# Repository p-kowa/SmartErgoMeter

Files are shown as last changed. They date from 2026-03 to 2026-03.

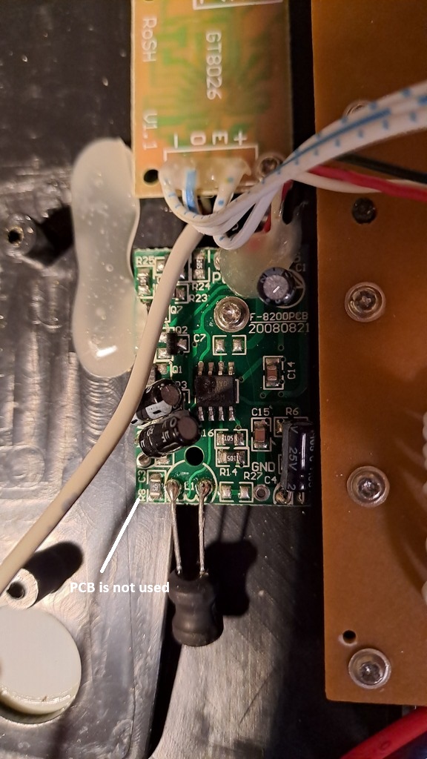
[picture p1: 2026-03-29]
pictures/chest strap receiver for pulse measurement.jpg

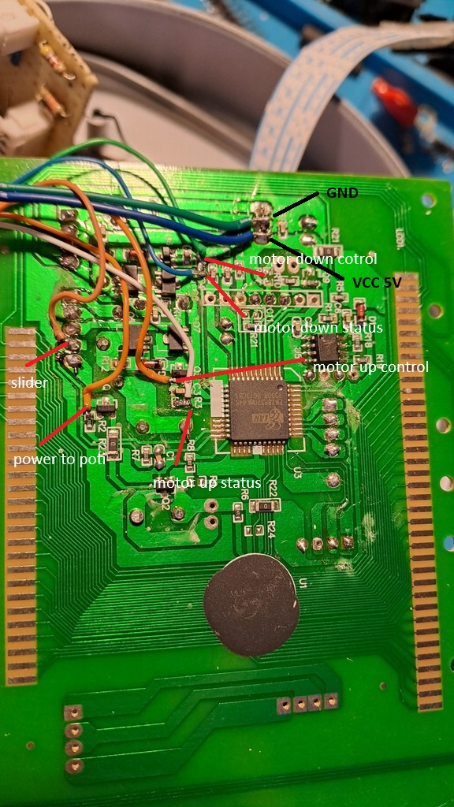
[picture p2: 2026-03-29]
pictures/wiring .jpg

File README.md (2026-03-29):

# SmartErgoMeter — Hammer Cardio XT5 Smart Trainer

Converts a **Hammer Cardio XT5** ergometer into a smart trainer compatible with fitness apps like **KinoMap**, **Zwift**, **Rouvy** etc. via BLE FTMS (Fitness Machine Service).

## Hardware

### Microcontroller
- **ESP32-C3 SuperMini** (tested ✅)
- **ESP32-S3 Zero** (target platform)

### Ergometer Components Used
The original ergometer PCB (EM78P510 controller) is left **untouched**. The ESP32 add-on board taps into existing signals.

| Component | Description |
|---|---|
| Reed contact | Speed + cadence sensor on crank (1 pulse = 1 revolution) |
| Heart rate sensor | 5V digital pulse output |
| Potentiometer | Resistance position feedback; PNP transistor on original PCB switches its supply |
| DC motor H-bridge | Original NPN H-bridge on PCB; ESP32 drives transistor bases via 8.2kΩ |
| EM78P510 MCU | Original controller; coexists via OR circuit and high-Z motor pins |

### External Circuit (add-on board)
| Component | Purpose |
|---|---|
| **BAT43** Schottky ×2 | OR-circuit: EM78-OUT1 + EM78-OUT2 → GPIO1 (EM78 activity detect) |
| **33kΩ / 68kΩ resistors** | Voltage divider: poti wiper (max ~5V) → GPIO3 (max 3.37V, safe for ESP32) |
| **10kΩ resistor** | Series resistor: reed contact line (4.7V) → GPIO2 (protects ESP32, no divider to GND) |
| **10kΩ / 18kΩ resistors** | Voltage divider: HR sensor output (5V) → GPIO7 |
| **8.2kΩ resistor ×2** | Motor base resistors: GPIO10 → H-bridge T1 base, GPIO20 → H-bridge T2 base |
| **8.2kΩ + 100kΩ resistors** | EM78_ACTIVE signal: BAT43 output → 8.2kΩ → GPIO1 → 100kΩ → GND |

### Pin Mapping
| GPIO | Signal | Notes |
|---|---|---|
| 1 | EM78_ACTIVE | OR: EM78-OUT1 + EM78-OUT2 via 2× BAT43 → 8.2kΩ → GPIO1, 100kΩ pulldown |
| 2 | Reed contact | 4.7V line via 10kΩ series, INPUT_PULLUP, FALLING interrupt |
| 3 | Potentiometer (ADC) | Wiper via 33kΩ/68kΩ divider → max 3.37V |
| 5 | Poti enable (PNP base) | Active LOW: GPIO5 LOW → PNP on → poti powered |
| 7 | Heart rate sensor | 5V via 10kΩ/18kΩ divider, INPUT, RISING interrupt |
| 10 | Motor IN_DOWN | HIGH → reduces resistance; 8.2kΩ to H-bridge transistor base |
| 20 | Motor IN_UP | HIGH → increases resistance; 8.2kΩ to H-bridge transistor base |

### Wiring Diagram
```
ESP32
│
├── GPIO2  ──[10kΩ]──────────── Reed contact line (4.7V from original PCB)
│           (INPUT_PULLUP)      (no divider to GND, EM78P510 stays unloaded)
│
├── GPIO7  ──[10kΩ]──┬───────── HR sensor output (5V)
│                    └─[18kΩ]── GND
│
├── GPIO3  ──────────┬───────── Poti wiper (via original PCB PNP switch)
│          [33kΩ between wiper and junction]
│                    └─[68kΩ]── GND
│
├── GPIO5  ── PNP base (on original PCB, via existing base resistor)
│           LOW = PNP on → poti powered
│           HIGH = PNP off → poti unpowered
│           (EM78P510 also drives same PNP via its own resistor)
│
├── GPIO1  ──[8.2kΩ]──┬─[BAT43]── EM78P510 Motor-OUT1
│          [100kΩ]    └─[BAT43]── EM78P510 Motor-OUT2
│           to GND                 (OR circuit: HIGH = EM78 driving motor)
│
├── GPIO10 ──[8.2kΩ]──────────── H-bridge transistor 1 base (Motor DOWN)
├── GPIO20 ──[8.2kΩ]──────────── H-bridge transistor 2 base (Motor UP)
│           KINOMAP: OUTPUT (ESP32 drives)
│           MANUAL:  INPUT / high-Z (EM78P510 has full control)
```

## Software

### BLE FTMS Profile
The device advertises as a **Fitness Machine Service (0x1826)** Indoor Bike with:

| Characteristic | UUID | Properties |
|---|---|---|
| Fitness Machine Feature | 0x2ACC | READ |
| Indoor Bike Data | 0x2AD2 | NOTIFY (1/sec) |
| Training Status | 0x2AD3 | NOTIFY, READ |
| Supported Resistance Level Range | 0x2AD6 | READ |
| Fitness Machine Control Point | 0x2AD9 | WRITE, INDICATE |
| Fitness Machine Status | 0x2ADA | NOTIFY |

Device name: `FTMSXXXXXXXX` (4 bytes of BLE MAC address)

### Control Modes
| Mode | Active when | Motor control |
|---|---|---|
| **KINOMAP** | BLE connected | ESP32 drives motor to target position via potentiometer feedback |
| **MANUAL** | BLE disconnected | EM78P510 buttons control motor (motor pins set to high-Z) |

When BLE connects → ESP32 gets priority (KINOMAP mode)  
When BLE disconnects → EM78P510 buttons take over (MANUAL mode)

Collision protection: if EM78_ACTIVE goes HIGH while ESP32 is driving, motor stops immediately.

### Supported FTMS Opcodes
| OpCode | Function |
|---|---|
| 0x00 | Request Control |
| 0x07 | Start / Resume |
| 0x08 | Stop / Pause |
| 0x04 | Set Target Resistance Level (SINT16, resolution 0.1, value 0–1000 = 0–100%) |
| 0x11 | Set Indoor Bike Simulation Parameters (grade → resistance mapping) |

### Calibration

The following values are calibrated for this specific Hammer Cardio XT5 unit:

```cpp
// Effective distance per crank revolution (reed is on crank, 1 pulse = 1 rev)
// Gear ratio is implicitly included — no separate GEAR_RATIO needed
// Calibration: WHEEL_CIRCUMFERENCE_MM = current_value × (display_km_h / app_km_h)
#define WHEEL_CIRCUMFERENCE_MM  6264.0   // calibrated (display=21.6 km/h, app=1.3 km/h → 377×16.6≈6264)

// Potentiometer ADC limits (12-bit: 0–4095)
// Drive motor to each end stop, read ADC from Serial: "Poti: X% (ADC=YYYY)"
#define POTI_ADC_MIN  1246   // ADC at minimum resistance end stop
#define POTI_ADC_MAX  4059   // ADC at maximum resistance end stop

// Grade → resistance mapping (OpCode 0x11)
// -10% to +20% grade → 0–100% resistance
// Adjust range after real route testing
```

## Development Setup

### Requirements
- [PlatformIO](https://platformio.org/) (VS Code extension)
- ESP32-C3 SuperMini or ESP32-S3 Zero board

### Build & Flash
```bash
# Build for ESP32-C3
pio run -e esp32-c3-devkitm-1

# Flash
pio run -e esp32-c3-devkitm-1 --target upload

# Debug build with USB CDC Serial Monitor
pio run -e esp32-c3-debug --target upload
pio device monitor -e esp32-c3-debug

# Build for ESP32-S3
pio run -e esp32-s3-devkitc-1 --target upload
```

### platformio.ini Environments
| Environment | Board | Purpose |
|---|---|---|
| `esp32-c3-devkitm-1` | ESP32-C3 | Main firmware (no USB CDC, stable BLE) |
| `esp32-c3-debug` | ESP32-C3 | With USB CDC for Serial Monitor |
| `esp32-s3-devkitc-1` | ESP32-S3 | Target platform |

### Testing without Hardware
Enable fake data mode in [src/Smartergometer.ino](src/Smartergometer.ino):
```cpp
#define FAKE_DATA 1
```
Generates synthetic speed, cadence and heart rate data for BLE testing with apps.

### Tested Apps
| App | Platform | Result |
|-----|---|---|
| nRF Connect | Android | ✅ Indoor Bike Data visible |
| KinoMap | Android / Fire TV | ✅ Resistance control working |

## Schematics
KiCad schematic files are in the [`schematics/`](schematics/) folder.

## Roadmap
- [ ] BLE Custom Characteristic for calibration (WHEEL_CIRCUMFERENCE, POTI_ADC_MIN/MAX) with NVS persistence
- [ ] Home Assistant integration
- [ ] Grade → resistance curve tuning after real route test

## License
MIT

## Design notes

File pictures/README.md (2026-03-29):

# Pictures — SmartErgoMeter

This folder contains reference photos of the hardware components and wiring used in the SmartErgoMeter project (Hammer Cardio XT5 Smart Trainer conversion).

## Contents

| File | Description |
|---|---|
| `buttons and reed.jpg` | Buttons on the ergometer and the reed contact used as speed/cadence sensor on the flywheel |
| `chest strap receiver for pulse measurement.jpg` | Heart rate receiver module that reads the 5V digital pulse signal from the chest strap. Not used in project. |
| `motor and reed.jpg` | DC motor responsible for resistance control together with the reed contact placement |
| `pulse.jpg` | Pulse/heart rate signal detail |
| `rotary potentiometer.jpg` | Rotary potentiometer used for resistance position feedback (only powered when motor runs) |
| `Temp PCB.jpg` | Temporary PCB / prototype circuit board with the external components (DRV8833, BS170, voltage dividers) |
| `wiring .jpg` | Overall wiring of the setup connecting the ESP32 to the ergometer components |

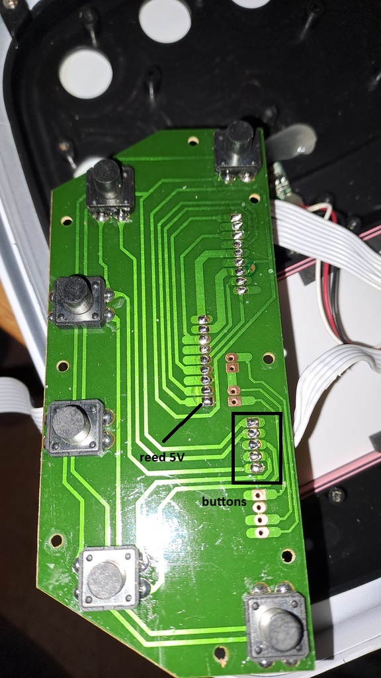
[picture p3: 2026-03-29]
pictures/buttons and reed.jpg

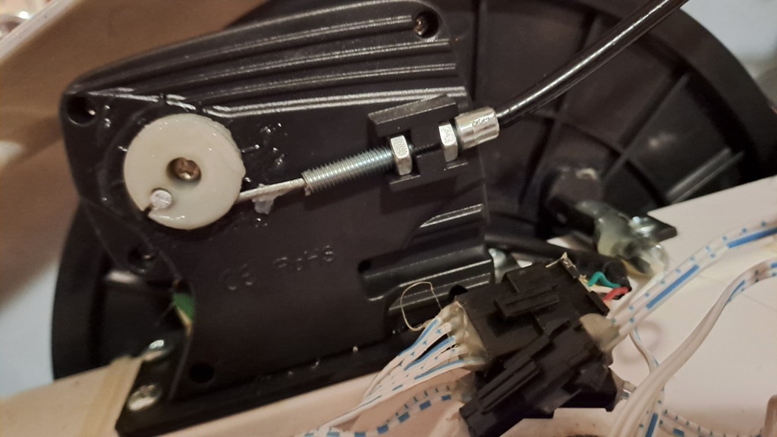
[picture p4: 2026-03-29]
pictures/motor and reed.jpg

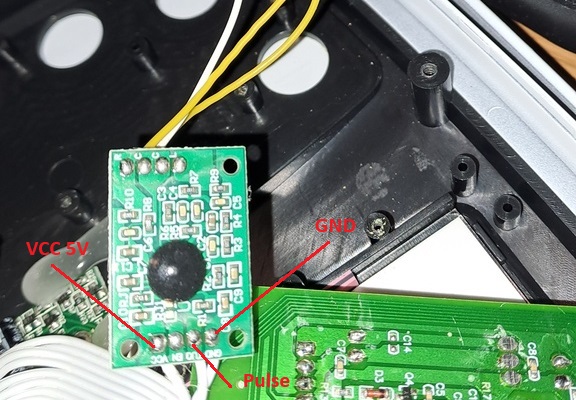
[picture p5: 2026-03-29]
pictures/pulse.jpg

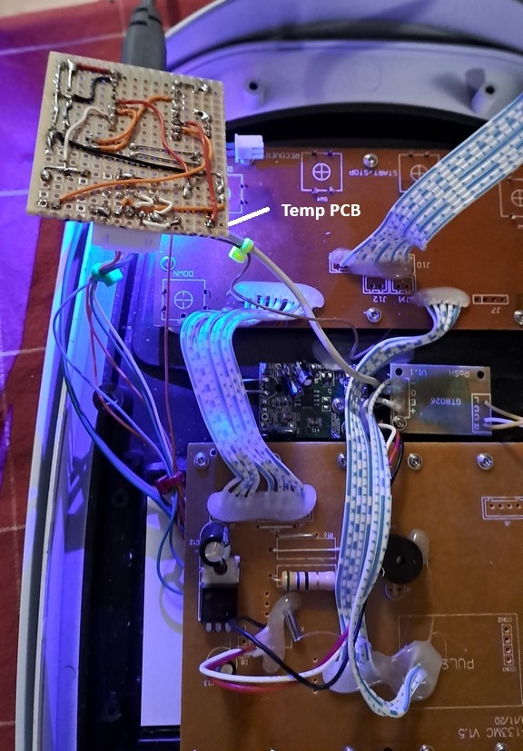
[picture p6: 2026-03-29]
pictures/Temp PCB.jpg

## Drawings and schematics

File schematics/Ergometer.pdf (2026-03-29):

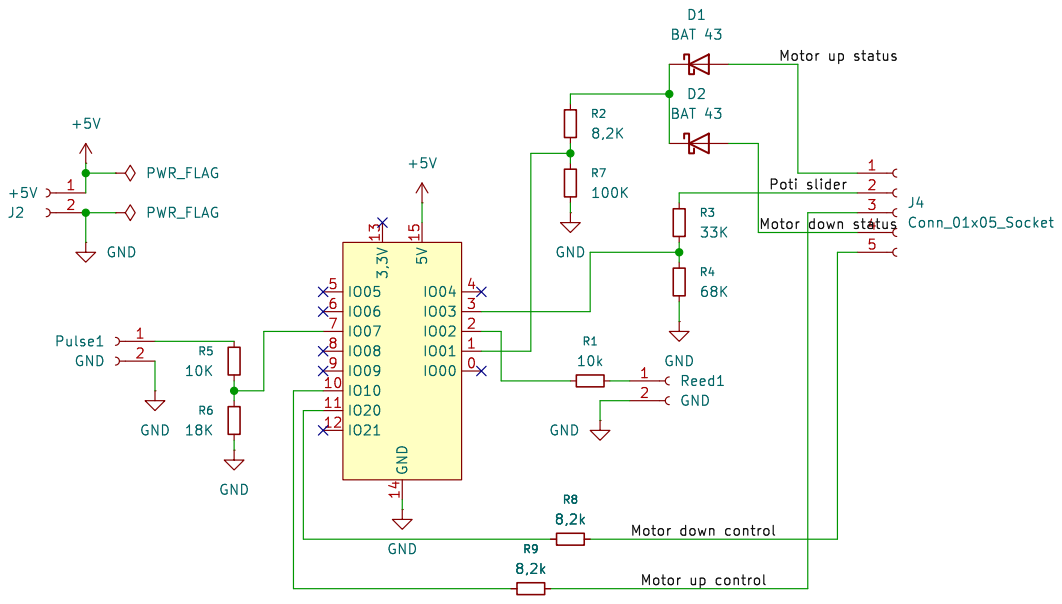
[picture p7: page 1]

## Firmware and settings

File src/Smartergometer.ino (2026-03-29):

#include <BLEDevice.h>
#include <BLEServer.h>
#include <BLEUtils.h>
#include <BLE2902.h>
#include <math.h>
#include "esp_mac.h"

#define FAKE_DATA 0                    // 1 = test data, 0 = real sensors

boolean serial_debug         = true;  // false when no PC connected
boolean write_startup_message = true;

// Effective distance per crank revolution (reed is on the crank, 1 pulse = 1 revolution)
// Implicitly includes the ergometer gear ratio → no separate GEAR_RATIO needed
// Calibration: WHEEL_CIRCUMFERENCE_MM = current_value × (display_km_h / app_km_h)
// Measured: display=21.6 km/h, app=1.3 km/h → 377 × (21.6/1.3) ≈ 6264 mm
#define WHEEL_CIRCUMFERENCE_MM  6264.0

// Rider weight in kg (used for power calculation)
#define RIDER_WEIGHT_KG  80.0

// Potentiometer ADC limits (0-4095)
// Calibration: drive motor manually to each end stop, read raw ADC from Serial Monitor
// Serial output: "Poti: X% (ADC=YYYY)" → note YYYY at minimum and maximum end stop
#define POTI_ADC_MIN     1246  // ADC value at minimum resistance (measured: 1245-1247)
#define POTI_ADC_MAX     4059  // ADC value at maximum resistance (measured: 4058-4060)

// ============================================================
// PIN DEFINITIONS (ESP32-S3)
// ============================================================
#define PIN_REED        2    // Reed contact → speed + cadence
                             // Hardware: reed line (4.7V) ──10kΩ──GPIO2
                             // 10kΩ series resistor protects ESP32 (max 3.6V)
                             // No divider to GND → EM78P510 remains unloaded
                             // GPIO6=JTAG/MOSI on ESP32-C3 → spurious interrupts, use GPIO2 instead
#define PIN_HEARTRATE   7    // Heart rate sensor (5V via 10k/18k divider) - GPIO7 works
#define PIN_POTI        3    // ADC potentiometer wiper
                             // Hardware: poti wiper ──32kΩ──GPIO3──66kΩ──GND (voltage divider)
                             // Poti VCC ~5V → divider: 5V × 66/(32+66) = 3.34V → safe for ESP32 (max 3.6V)
#define PIN_POTI_EN     5    // PNP transistor base control (active LOW!)
                             // GPIO5 LOW  → PNP conducts → poti powered (measurement)
                             // GPIO5 HIGH → PNP off → poti unpowered (idle)
                             // EM78P510 also drives PNP via 10kΩ → both share the transistor
                             // Contention non-critical: 10kΩ + 12kΩ in series (~0.2mA)
#define PIN_EM78_ACTIVE 1    // EM78P510 active (OR: motor-OUT1 + motor-OUT2 via 2× BAT43 → GPIO1)
                             // GPIO8 = RGB LED on C3 Super Mini → do not use!
                             // Hardware: EM78-OUT1 ──BAT43──┐
                             //           EM78-OUT2 ──BAT43──┴──8.2kΩ──GPIO1──100kΩ──GND
                             // 5V - 0.35V(BAT43) = 4.65V → clamp diode: 0.16mA → safe
                             // HIGH = EM78P510 driving motor → ESP32 must stop immediately
#define PIN_MOTOR_IN_DOWN   10   // H-bridge transistor 1 base (ESP32 via 8.2kΩ, EM78P510 via 10kΩ)
#define PIN_MOTOR_IN_UP     20   // H-bridge transistor 2 base (ESP32 via 8.2kΩ, EM78P510 via 10kΩ)
                             // KINOMAP: OUTPUT (ESP32 drives HIGH/LOW)
                             // MANUAL:  INPUT  (high-Z → EM78P510 has full control)

// ============================================================
// MOTOR CONTROL
// ============================================================
enum ControlMode { KINOMAP, MANUAL };
ControlMode motorMode        = MANUAL; // On startup without BLE: manual
int targetResistance         = 0;      // 0-100% target resistance from KinoMap
int currentResistance        = 0;      // Current position (from poti)
unsigned long lastMotorCmd   = 0;
#define MOTOR_TIMEOUT        5000      // ms without KinoMap command → switch back to MANUAL
#define POTI_TOLERANCE       80        // ADC tolerance band (0-4095)
#define MOTOR_DRIVE_INTERVAL 50        // ms between poti readings while driving

void motorDown() {
  pinMode(PIN_MOTOR_IN_DOWN, OUTPUT);
  pinMode(PIN_MOTOR_IN_UP, OUTPUT);
  digitalWrite(PIN_MOTOR_IN_DOWN, HIGH);
  digitalWrite(PIN_MOTOR_IN_UP, LOW);
}

void motorUp() {
  pinMode(PIN_MOTOR_IN_DOWN, OUTPUT);
  pinMode(PIN_MOTOR_IN_UP, OUTPUT);
  digitalWrite(PIN_MOTOR_IN_DOWN, LOW);
  digitalWrite(PIN_MOTOR_IN_UP, HIGH);
}

void motorStop() {
  digitalWrite(PIN_MOTOR_IN_DOWN, LOW);
  digitalWrite(PIN_MOTOR_IN_UP, LOW);
  pinMode(PIN_MOTOR_IN_DOWN, INPUT);  // high-Z → EM78P510 can control freely
  pinMode(PIN_MOTOR_IN_UP, INPUT);
}

// Briefly power poti and read ADC
// PNP logic: LOW = ON, HIGH = OFF
int readPotiPosition() {
  digitalWrite(PIN_POTI_EN, LOW);   // turn PNP on → power poti
  delay(5);
  int val = analogRead(PIN_POTI);
  digitalWrite(PIN_POTI_EN, HIGH);  // turn PNP off → unpower poti
  return val; // 0-4095
}

// Drive motor to target position (blocking, max 5 sec)
// Aborts immediately if EM78P510 presses a button (collision protection)
void driveToPosition(int targetPct) {
  int targetAdc  = map(targetPct, 0, 100, POTI_ADC_MIN, POTI_ADC_MAX);
  unsigned long startTime = millis();

  while (millis() - startTime < 5000) {

    // Collision protection: EM78P510 active → stop immediately
    if (digitalRead(PIN_EM78_ACTIVE)) {
      motorStop();
      if (serial_debug) Serial.println("Motor: EM78P510 active, motor stopped!");
      return;
    }

    int currentAdc = readPotiPosition();
    currentResistance = map(constrain(currentAdc, POTI_ADC_MIN, POTI_ADC_MAX), POTI_ADC_MIN, POTI_ADC_MAX, 0, 100);

    if (abs(currentAdc - targetAdc) <= POTI_TOLERANCE) {
      motorStop();
      if (serial_debug) {
        Serial.printf("Motor: target reached %d%% (ADC=%d)\n", targetPct, currentAdc);
      }
      return;
    }

    if (currentAdc < targetAdc) motorUp();
    else                        motorDown();

    delay(MOTOR_DRIVE_INTERVAL);
  }

  motorStop(); // timeout
  if (serial_debug) Serial.println("Motor: timeout!");
}

// MANUAL mode: EM78P510 drives motor directly via its own H-bridge
// Motor pins kept high-Z so there is no conflict
// Called once on mode transition, not every loop iteration
void handleManualMode() {
  static ControlMode lastMode = KINOMAP;
  if (lastMode != MANUAL) {
    motorStop(); // set high-Z only on transition
    lastMode = MANUAL;
  }
}

void resetManualModeTracker() {
  // Call when switching to KINOMAP so next MANUAL transition triggers motorStop()
  // (handled implicitly since lastMode is static)
}

// ============================================================
// SENSORS
// ============================================================
volatile unsigned long speed_counter          = 0;
volatile unsigned long speed_timer            = 0;
unsigned long          speed_counter_prev     = 0;
unsigned long          speed_timer_prev       = 0;
double                 instantaneous_speed    = 0; // m/s

volatile unsigned long cadence_timer          = 0;
volatile unsigned long cadence_previous_timer = 0;
unsigned int           instantaneous_cadence  = 0; // RPM

volatile unsigned long hr_timer               = 0;
volatile unsigned long hr_previous_timer      = 0;
uint8_t                HeartRate              = 0;

double instantaneous_power = 0;
float  grade               = 0;
float  wind_speed          = 0;
float  crr                 = 0;
float  cw                  = 0;

// Reed contact interrupt → speed + cadence
// Debounce 50ms: prevents multiple triggers from contact bounce
void IRAM_ATTR reedInterrupt() {
  unsigned long now = millis();
  if (now - speed_timer < 50) return;  // debounce
  speed_counter++;
  speed_timer            = now;
  cadence_previous_timer = cadence_timer;
  cadence_timer          = now;
}

// Heart rate interrupt
void IRAM_ATTR heartRateInterrupt() {
  hr_previous_timer = hr_timer;
  hr_timer          = millis();
}

double calculateSpeed() {
  // Not yet two valid measurements available
  if (speed_timer == 0 || speed_timer_prev == 0) return 0.0;
  // No signal for >3 sec → speed = 0
  if (millis() - speed_timer > 3000) return 0.0;
  if (speed_timer == speed_timer_prev) return 0.0;
  unsigned long delta_count = speed_counter - speed_counter_prev;
  unsigned long delta_time  = speed_timer   - speed_timer_prev;
  if (delta_count == 0 || delta_time == 0 || delta_time > 5000) return 0.0;
  return (delta_count * WHEEL_CIRCUMFERENCE_MM / 1000.0) / (delta_time / 1000.0); // m/s
}

unsigned int calculateCadence() {
  // Reed on crank → 1 pulse = 1 crank revolution → direct RPM
  unsigned long interval = cadence_timer - cadence_previous_timer;
  if (interval < 200 || interval > 5000) return 0;
  return (unsigned int)round(60000.0 / interval);
}

uint8_t calculateHeartRate() {
  // No signal for >3 sec → HR = 0 (hands off sensor)
  if (millis() - hr_timer > 3000) return 0;
  unsigned long interval = hr_timer - hr_previous_timer;
  if (interval < 300 || interval > 3000) return 0;
  return (uint8_t)(60000 / interval);
}

double calculatePower(double speed_ms) {
  if (speed_ms < 0.1) return 0;
  const int   ELEVATION = 40;
  double rho  = 1.225 * exp(-0.00011856 * ELEVATION);
  float  cdA  = 0.324;
  double w    = RIDER_WEIGHT_KG;
  return speed_ms * (
    (w * 9.80655 * sin(atan(grade / 100.0))) +
    (crr * w * 9.80655 * cos(atan(grade / 100.0))) +
    (0.5 * cdA * rho * pow(speed_ms + wind_speed, 2))
  );
}

// ============================================================
// BLE FTMS
// ============================================================
#define FMCP_DATA_SIZE 19

typedef struct __attribute__((packed)) {
  uint8_t OPCODE;
  uint8_t OCTETS[FMCP_DATA_SIZE - 1];
} fmcp_data_t;

typedef union {
  fmcp_data_t values;
  uint8_t     bytes[FMCP_DATA_SIZE];
} fmcp_data_ut;

fmcp_data_ut fmcpData;
short        fmcpValueLength          = 0;
volatile long lastControlPointEvent   = 0;
long          previousControlPointEvent = 0;

// Feature flags
// Bytes 0-3: Fitness Machine Features  (cadence, resistance, power, HR)
// Bytes 4-7: Target Setting Features   (bit2=ResistanceLevel, bit7=SimulationParams)
unsigned char ftmfBuffer[8] = { 0b10000111, 0b01000100, 0, 0,
                                 0b10000100, 0,          0, 0 };
unsigned char ibdBuffer[9]  = { 0, 0, 0, 0, 0, 0, 0, 0, 0 };
unsigned char srlrBuffer[6] = { 0x00, 0x00,   // Min = 0   (× 0.1 = 0.0)
                                0xE8, 0x03,   // Max = 1000 (× 0.1 = 100.0)
                                0x0A, 0x00 }; // Step = 10  (× 0.1 = 1.0%)
unsigned char ftmsBuffer[2] = { 0, 0 };
unsigned char tsBuffer[2]   = { 0x00, 0x00 };
unsigned char ftmcpBuffer[20];

// Indoor Bike Data Flags
const uint16_t flagInstantaneousCadence = 4;
const uint16_t flagIntantaneousPower    = 64;
const uint16_t flagHeartRate            = 512;

// FMCP Opcodes
const uint8_t fmcpRequestControl                       = 0x00;
const uint8_t fmcpReset                                = 0x01;
const uint8_t fmcpSetTargetSpeed                       = 0x02;
const uint8_t fmcpSetTargetInclination                 = 0x03;
const uint8_t fmcpSetTargetResistanceLevel             = 0x04;
const uint8_t fmcpSetTargetPower                       = 0x05;
const uint8_t fmcpSetTargetHeartRate                   = 0x06;
const uint8_t fmcpStartOrResume                        = 0x07;
const uint8_t fmcpStopOrPause                          = 0x08;
const uint8_t fmcpSetIndoorBikeSimulationParameters    = 0x11;
const uint8_t fmcpResponseCode                         = 0x80;

int  ble_connected = LOW;

BLEServer         *pServer                        = nullptr;
BLECharacteristic *pFitnessMachineFeature         = nullptr;
BLECharacteristic *pIndoorBikeData                = nullptr;
BLECharacteristic *pTrainingStatus                = nullptr;
BLECharacteristic *pSupportedResistanceLevelRange = nullptr;
BLECharacteristic *pFitnessMachineControlPoint    = nullptr;
BLECharacteristic *pFitnessMachineStatus          = nullptr;

class ServerCallbacks : public BLEServerCallbacks {
  void onConnect(BLEServer *pSrv) override {
    ble_connected = HIGH;
    motorMode     = KINOMAP; // BLE connected → ESP32 takes control
    rgbLedWrite(RGB_BUILTIN, 0, 0, RGB_BRIGHTNESS); // blue
    if (serial_debug) Serial.println("BLE connected → KINOMAP mode");
  }
  void onDisconnect(BLEServer *pSrv) override {
    ble_connected = LOW;
    motorMode     = MANUAL;  // BLE disconnected → EM78P510 buttons active
    motorStop();
    rgbLedWrite(RGB_BUILTIN, RGB_BRIGHTNESS, RGB_BRIGHTNESS, 0); // yellow
    BLEDevice::getAdvertising()->start();
    if (serial_debug) Serial.println("BLE disconnected → MANUAL mode");
  }
};

class ControlPointCallbacks : public BLECharacteristicCallbacks {
  void onWrite(BLECharacteristic *pChar) override {
    fmcpValueLength = pChar->getLength();
    memset(fmcpData.bytes, 0, sizeof(fmcpData.bytes));
    memcpy(fmcpData.bytes, pChar->getData(), fmcpValueLength);
    lastControlPointEvent = millis();
  }
};

// Training Status
enum status_t { STOPPED, RUNNING, PAUSED };
unsigned short training_status = STOPPED;

const short   NOTIFICATION_INTERVAL = 1000;
long          previous_notification  = 0;
long          current_millis         = 0;

// ============================================================
// SETUP
// ============================================================
void setup() {
  if (serial_debug) {
    Serial.begin(115200);
    delay(1000);
    Serial.println("SmartErgoMeter starting...");
  }

  rgbLedWrite(RGB_BUILTIN, RGB_BRIGHTNESS, RGB_BRIGHTNESS, 0); // yellow = startup

  // Motor pins: high-Z on startup (MANUAL mode, EM78P510 has priority)
  pinMode(PIN_MOTOR_IN_DOWN, INPUT);
  pinMode(PIN_MOTOR_IN_UP, INPUT);

  // EM78P510 activity detection (OR: motor-OUT1 + motor-OUT2 via 2× BAT43)
  pinMode(PIN_EM78_ACTIVE, INPUT);

  // Poti enable (PNP base, active LOW)
  pinMode(PIN_POTI_EN, OUTPUT);
  digitalWrite(PIN_POTI_EN, HIGH);  // PNP off → poti unpowered on startup

  // Reed contact (speed + cadence)
  pinMode(PIN_REED, INPUT_PULLUP);
  attachInterrupt(digitalPinToInterrupt(PIN_REED), reedInterrupt, FALLING);

  // Heart rate
  pinMode(PIN_HEARTRATE, INPUT);
  attachInterrupt(digitalPinToInterrupt(PIN_HEARTRATE), heartRateInterrupt, RISING);

  // BLE Setup
  uint8_t mac[6];
  esp_read_mac(mac, ESP_MAC_BT);
  char deviceName[30];
  sprintf(deviceName, "FTMS%02X%02X%02X%02X", mac[2], mac[3], mac[4], mac[5]);

  BLEDevice::init(deviceName);
  pServer = BLEDevice::createServer();
  pServer->setCallbacks(new ServerCallbacks());

  BLEService *pFTMSService = pServer->createService(BLEUUID((uint16_t)0x1826));

  pFitnessMachineFeature         = pFTMSService->createCharacteristic(BLEUUID((uint16_t)0x2ACC), BLECharacteristic::PROPERTY_READ);
  pIndoorBikeData                = pFTMSService->createCharacteristic(BLEUUID((uint16_t)0x2AD2), BLECharacteristic::PROPERTY_NOTIFY);
  pIndoorBikeData->addDescriptor(new BLE2902());
  pTrainingStatus                = pFTMSService->createCharacteristic(BLEUUID((uint16_t)0x2AD3), BLECharacteristic::PROPERTY_NOTIFY | BLECharacteristic::PROPERTY_READ);
  pTrainingStatus->addDescriptor(new BLE2902());
  pSupportedResistanceLevelRange = pFTMSService->createCharacteristic(BLEUUID((uint16_t)0x2AD6), BLECharacteristic::PROPERTY_READ);
  pFitnessMachineControlPoint    = pFTMSService->createCharacteristic(BLEUUID((uint16_t)0x2AD9), BLECharacteristic::PROPERTY_WRITE | BLECharacteristic::PROPERTY_INDICATE);
  pFitnessMachineControlPoint->addDescriptor(new BLE2902());
  pFitnessMachineStatus          = pFTMSService->createCharacteristic(BLEUUID((uint16_t)0x2ADA), BLECharacteristic::PROPERTY_NOTIFY);
  pFitnessMachineStatus->addDescriptor(new BLE2902());

  pFitnessMachineFeature->setValue(ftmfBuffer, 8);
  pIndoorBikeData->setValue(ibdBuffer, sizeof(ibdBuffer));
  pSupportedResistanceLevelRange->setValue(srlrBuffer, 6);
  pFitnessMachineStatus->setValue(ftmsBuffer, 2);
  pTrainingStatus->setValue(tsBuffer, 2);
  pFitnessMachineControlPoint->setCallbacks(new ControlPointCallbacks());

  pFTMSService->start();

  BLEAdvertising *pAdvertising = BLEDevice::getAdvertising();
  pAdvertising->addServiceUUID(BLEUUID((uint16_t)0x1826));
  pAdvertising->start();

  if (serial_debug) Serial.printf("BLE started: %s\n", deviceName);

}

// ============================================================
// LOOP
// ============================================================
void loop() {

#if FAKE_DATA
  static unsigned long fake_tick;
  static unsigned long fake_duration = 900;
  static int           fake_increase = 50;
  static bool          led_toggle;
  static unsigned long led_tick;

  if (millis() - led_tick > 500) {
    led_tick = millis();
    if (ble_connected == LOW) {
      rgbLedWrite(RGB_BUILTIN,
        RGB_BRIGHTNESS, RGB_BRIGHTNESS,
        led_toggle ? 0 : RGB_BRIGHTNESS);
    }
    led_toggle = !led_toggle;
  }

  if (millis() - fake_tick >= fake_duration) {
    fake_tick = millis();
    speed_counter++;
    speed_timer            = millis();
    cadence_previous_timer = cadence_timer;
    cadence_timer          = millis();
    hr_previous_timer      = hr_timer;
    hr_timer               = millis() - 857; // ~70 BPM

    fake_duration += fake_increase;
    if (fake_duration >= 1100) fake_increase = -50;
    else if (fake_duration <= 600) fake_increase = 50;
  }
#endif

  // ---- Motor control ----
  if (motorMode == KINOMAP) {
    // ESP32 has priority → maintain target position
    // driveToPosition() is called from handleControlPoint()
  } else {
    // MANUAL: EM78P510 drives motor directly, keep pins high-Z
    handleManualMode();
  }

  // ---- BLE notifications ----
  current_millis = millis();
  if (current_millis > previous_notification + NOTIFICATION_INTERVAL) {

    // Calculate sensor values (always, to keep snapshots current)
    instantaneous_speed   = calculateSpeed();
    instantaneous_cadence = calculateCadence();
    HeartRate             = calculateHeartRate();
    instantaneous_power   = calculatePower(instantaneous_speed);

    // Always update counter snapshots (prevents accumulation)
    speed_counter_prev = speed_counter;
    speed_timer_prev   = speed_timer;
    previous_notification = millis();

    // Read current poti position
    int potiRaw = readPotiPosition();
    currentResistance = map(constrain(potiRaw, POTI_ADC_MIN, POTI_ADC_MAX), POTI_ADC_MIN, POTI_ADC_MAX, 0, 100);

    if (ble_connected == HIGH) {
      writeIndoorBikeDataCharacteristic();
    }
  }

  // ---- Control point handler ----
  if (previousControlPointEvent != lastControlPointEvent) {
    handleControlPoint();
    previousControlPointEvent = lastControlPointEvent;
  }
}

// ============================================================
// BLE: Write Indoor Bike Data characteristic
// ============================================================
void writeIndoorBikeDataCharacteristic() {
  // Flags: instantaneous cadence + power + heart rate
  uint16_t flags = flagInstantaneousCadence | flagIntantaneousPower | flagHeartRate;
  ibdBuffer[0] = flags & 0xFF;
  ibdBuffer[1] = (flags >> 8) & 0xFF;

  // Speed: km/h * 100 (uint16, resolution 0.01 km/h)
  int s = round(instantaneous_speed * 3.6 * 100.0);
  ibdBuffer[2] = s & 0xFF;
  ibdBuffer[3] = (s >> 8) & 0xFF;

  // Cadence: RPM * 2 (uint16, resolution 0.5 rpm)
  int c = instantaneous_cadence * 2;
  ibdBuffer[4] = c & 0xFF;
  ibdBuffer[5] = (c >> 8) & 0xFF;

  // Power: watts (sint16)
  int p = round(instantaneous_power);
  ibdBuffer[6] = p & 0xFF;
  ibdBuffer[7] = (p >> 8) & 0xFF;

  // Heart rate: BPM (uint8)
  ibdBuffer[8] = HeartRate;

  pIndoorBikeData->setValue(ibdBuffer, sizeof(ibdBuffer));
  pIndoorBikeData->notify();

  // Serial output intentionally removed from notify loop to avoid blocking BLE
}

// ============================================================
// BLE: Write Training Status characteristic
// ============================================================
void writeTrainingStatus() {
  switch (training_status) {
    case STOPPED:
      tsBuffer[0] = 0x02; tsBuffer[1] = 0x01;
      pTrainingStatus->setValue(tsBuffer, 2);
      pTrainingStatus->notify();
      break;
    case PAUSED:
      tsBuffer[0] = 0x02; tsBuffer[1] = 0x02;
      pTrainingStatus->setValue(tsBuffer, 2);
      pTrainingStatus->notify();
      break;
    case RUNNING:
      tsBuffer[0] = 0x04;
      pTrainingStatus->setValue(tsBuffer, 1);
      pTrainingStatus->notify();
      break;
  }
}
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

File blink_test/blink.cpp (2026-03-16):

// Minimaler Blink-Test für ESP32-C3 DevKitM-1
// RGB_BUILTIN = GPIO8 (WS2812), kein BLE, keine Libraries
#include <Arduino.h>

#define BRIGHTNESS 30  // 0-255, niedrig halten (WS2812 ist sehr hell)

void setup() {
  Serial.begin(115200);
  delay(500);
  Serial.println("ESP32-C3 Blink-Test gestartet");
}

void loop() {
  Serial.println("ROT");
  rgbLedWrite(RGB_BUILTIN, BRIGHTNESS, 0, 0);
  delay(1000);

  Serial.println("GRUEN");
  rgbLedWrite(RGB_BUILTIN, 0, BRIGHTNESS, 0);
  delay(1000);

  Serial.println("BLAU");
  rgbLedWrite(RGB_BUILTIN, 0, 0, BRIGHTNESS);
  delay(1000);

  Serial.println("AUS");
  rgbLedWrite(RGB_BUILTIN, 0, 0, 0);
  delay(500);
}

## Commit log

2026-03-16 Fix WHEEL_CIRCUMFERENCE_MM: 377mm (Magnet bei 6cm Radius)
2026-03-16 Rename: Smartergoeter.ino → Smartergometer.ino (Tippfehler)
2026-03-18 Refactor configuration and pin definitions; update motor control logic for EM78P510 integration
2026-03-20 Kalibrierung: WHEEL_CIRCUMFERENCE_MM=6264, GEAR_RATIO entfernt (Reed an Kurbel)
2026-03-22 Refactor potentiometer handling: update pin definitions, enable logic, and constrain ADC readings
2026-03-22 Update potentiometer ADC limits and adjust mapping in driveToPosition function
2026-03-22 Refactor motor control pin definitions and update wiring comments for EM78P510 integration
2026-03-24 Refactor motor control pin definitions for clarity and consistency
2026-03-24 Enhance serial output: include EM78 status and motor mode in potentiometer readings
2026-03-24 Add motor self-test routine in setup for wiring verification
2026-03-24 Fix device name formatting in BLE initialization and improve debug output for resistance control
    [Smartergometer.ino]
2026-03-24 Update resistance level range to support finer granularity and adjust target resistance mapping
2026-03-29 Add schematic for Ergometer in PDF format
    - Introduced a new schematic file (Ergometer.pdf) detailing the circuit design for the Ergometer project.
    - The schematic includes components such as power flags, resistors, and motor control statuses.
    - Documented by P. Kowalewski, with versioning and date included for reference.
    [Ergometer.kicad_sch]
2026-03-29 fix: update motor control pin resistor values for improved performance
    [Smartergometer.ino]
